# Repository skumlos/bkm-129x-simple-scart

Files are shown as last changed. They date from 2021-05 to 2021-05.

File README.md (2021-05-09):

The BKM-129X compatible with SCART instead of BNC.

Including a mono mixing circuit from SCART audio to RCA out, for monitors with internal audio in from option cards.

3D printable bracket here: https://www.thingiverse.com/thing:4460188

Requires Arduino Nano v3.0 loaded with the software from https://github.com/skumlos/bkm-129x-mcu

Revision history:

B: Fixed THS7374 filter bypass, change to Kicad 5

A: Initial revision

Copyright © 2020 Martin Hejnfelt <martin@hejnfelt.com>
This work is free. You can redistribute it and/or modify it under the
terms of the Do What The Fuck You Want To Public License, Version 2,
as published by Sam Hocevar. See the LICENSE file for more details.

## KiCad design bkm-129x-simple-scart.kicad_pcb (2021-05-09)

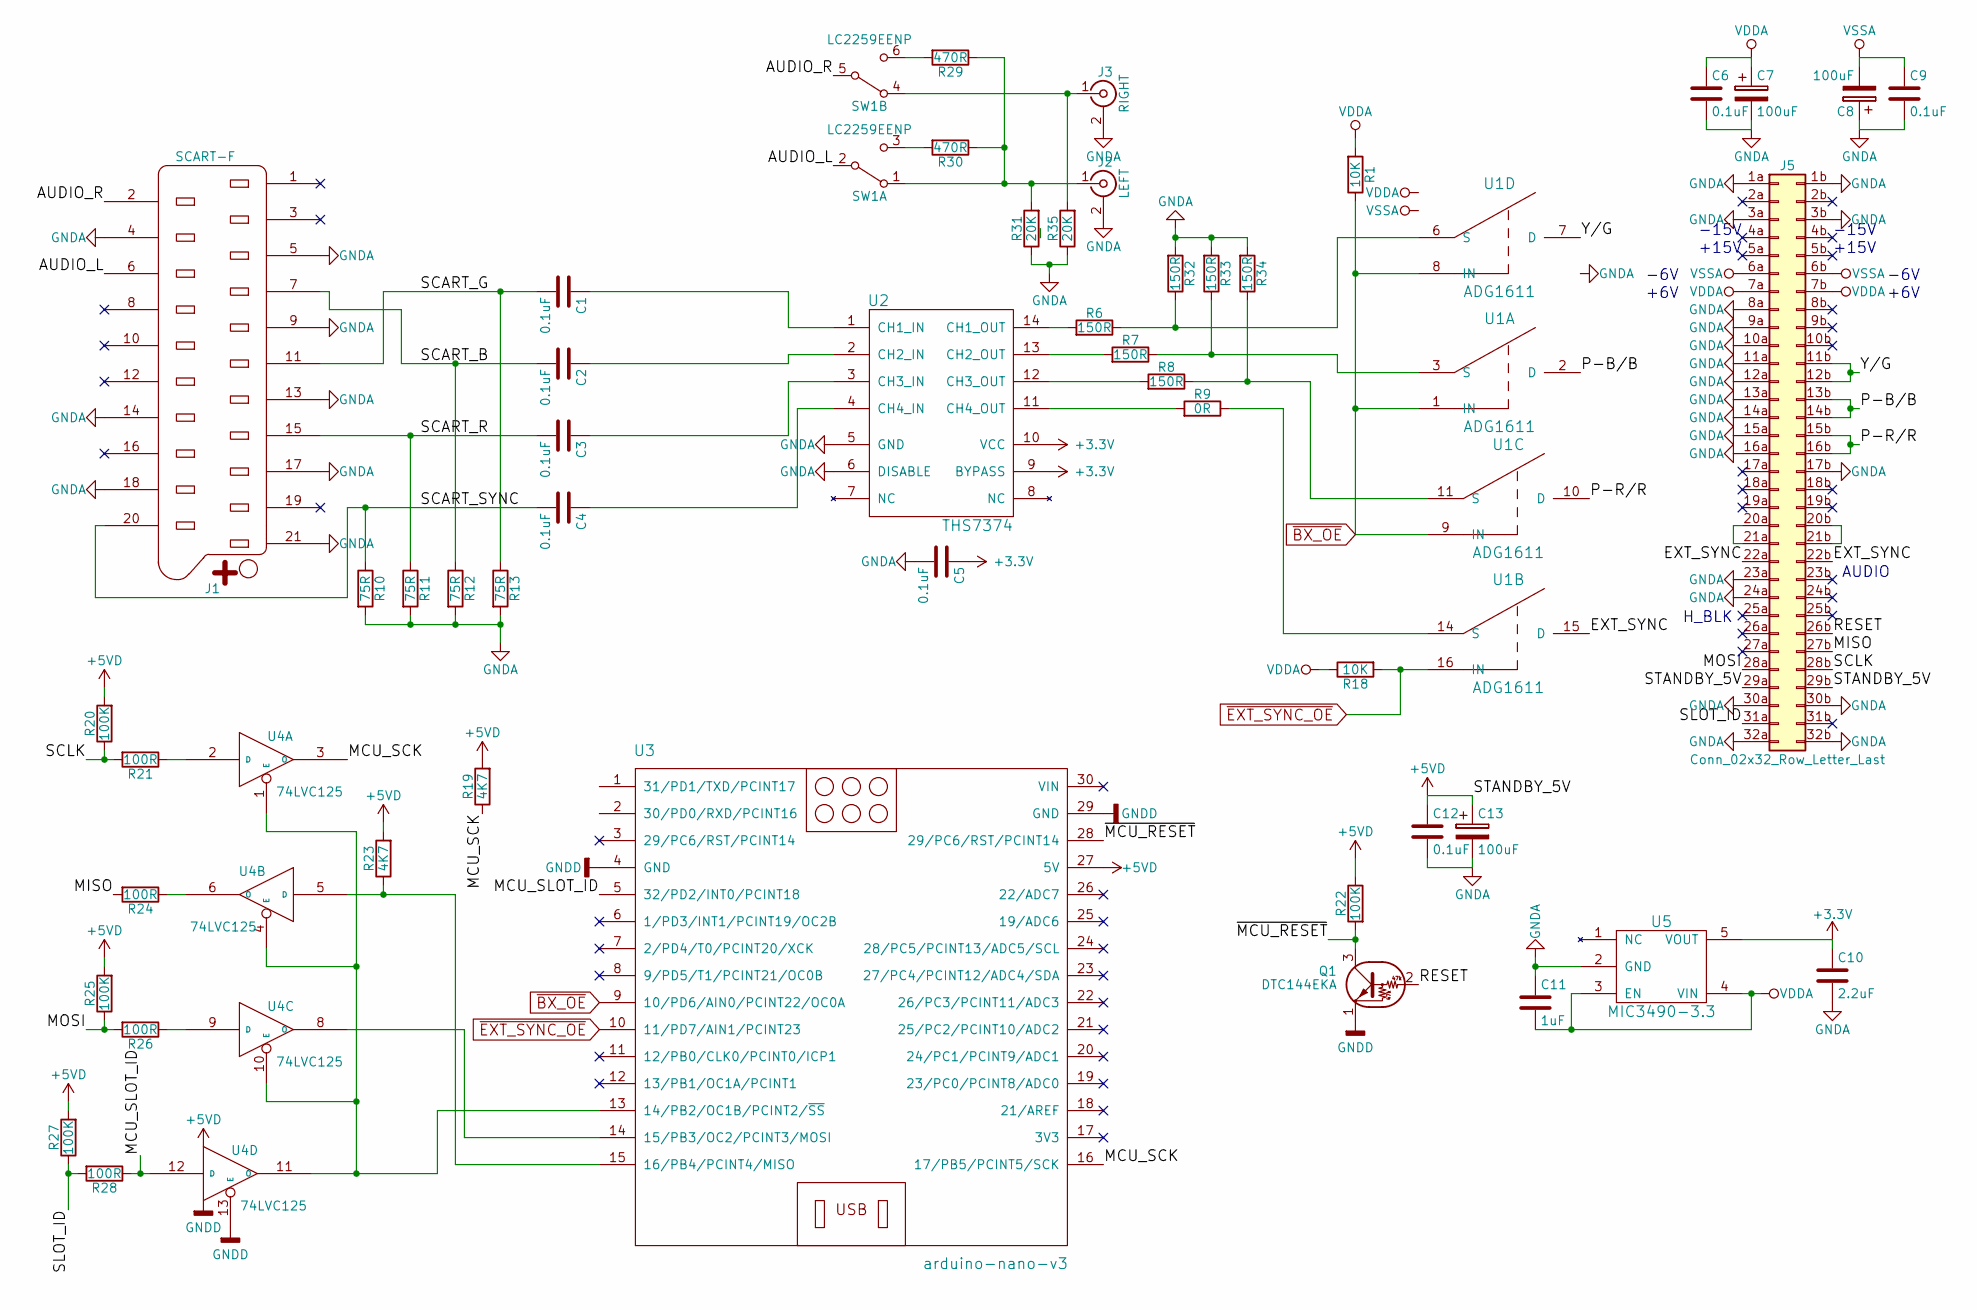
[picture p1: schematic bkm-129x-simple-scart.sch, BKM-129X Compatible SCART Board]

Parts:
C1, C2, C3, C4, C5, C6, C9, C12: 0.1uF; C_0805_HandSoldering
C7, C8, C13: 100uF; CP_Elec_6.3x5.3
C10: 2.2uF; C_0805_HandSoldering
C11: 1uF; C_0805_HandSoldering
J1: SCART-F; NINIGI-SCART-RA
J2: LEFT; RCJ-04X
J3: RIGHT; RCJ-04X
J5: Conn_02x32_Row_Letter_Last; DIN-41612-64P
Q1: DTC144EKA; SC-59_Handsoldering
R1, R18: 10K; R_0805_HandSoldering
R6, R7, R8, R32, R33, R34: 150R; R_0805_HandSoldering
R9: 0R; R_0805_HandSoldering
R10, R11, R12, R13: 75R; R_0805_HandSoldering
R19, R23: 4K7; R_0805_HandSoldering
R20, R22, R25, R27: 100K; R_0805_HandSoldering
R21, R24, R26, R28: 100R; R_0805_HandSoldering
R29, R30: 470R; R_0805_HandSoldering
R31, R35: 20K; R_0805_HandSoldering
SW1: LC2259EENP; LC2259
U1: ADG1611; TSSOP-16_4.4x5mm_Pitch0.65mm
U2: THS7374; TSSOP-14_4.4x5mm_Pitch0.65mm
U3: arduino-nano-v3
U4: 74LVC125; TSSOP-14_4.4x5mm_Pitch0.65mm
U5: MIC3490-3.3; SOT-23-5_HandSoldering

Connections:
+3V3: C5.1, C10.1, U2.9 (BYPASS), U2.10 (VCC), U5.5 (VOUT)
+5VD: C12.1, C13.1, J5.29a, J5.29b, R19.2, R20.2, R22.1, R23.2, R25.2, R27.2, U3.27 (5V), U4.14 (VCC)
/AUDIO_L: J1.6, SW1.2 (B)
/AUDIO_R: J1.2, SW1.5 (B)
/EXT_SYNC: J5.22a, J5.22b, U1.15 (D)
/MCU_SCK: R19.1, U3.16 (17/PB5/PCINT5/SCK), U4.3 (O)
/MCU_SLOT_ID: R28.1, U3.5 (32/PD2/INT0/PCINT18), U4.12 (D)
/MISO: J5.27b, R24.2
/MOSI: J5.28a, R25.1, R26.2
/P-B/B: J5.13b, J5.14b, U1.2 (D)
/P-R/R: J5.15b, J5.16b, U1.10 (D)
/RESET: J5.26b, Q1.2 (B)
/SCART_B: C2.2, J1.7, R12.1
/SCART_G: C1.2, J1.11, R13.1
/SCART_R: C3.2, J1.15, R11.1
/SCART_SYNC: C4.2, J1.20, R10.1
/SCLK: J5.28b, R20.1, R21.2
/SLOT_ID: J5.31a, R27.1, R28.2
/Y/G: J5.11b, J5.12b, U1.7 (D)
/~MCU_RESET: Q1.3 (C), R22.2, U3.28 (29/PC6/RST/PCINT14)
unnamed: C1.1, U2.1 (CH1_IN)
unnamed: C2.1, U2.2 (CH2_IN)
unnamed: C3.1, U2.3 (CH3_IN)
unnamed: C4.1, U2.4 (CH4_IN)
unnamed: J2.1 (In), R29.1, R30.1, R31.2, SW1.1 (A)
unnamed: J3.1 (In), R35.2, SW1.4 (A)
unnamed: J5.20a, J5.21a
unnamed: J5.20b, J5.21b
unnamed: R6.2, U2.14 (CH1_OUT)
unnamed: R7.2, U2.13 (CH2_OUT)
unnamed: R8.2, U2.12 (CH3_OUT)
unnamed: R9.1, U1.14 (S)
unnamed: R9.2, U2.11 (CH4_OUT)
unnamed: R21.1, U4.2 (D)
unnamed: R23.1, U3.15 (16/PB4/PCINT4/MISO), U4.5 (D)
unnamed: R24.1, U4.6 (O)
unnamed: R26.1, U4.9 (D)
unnamed: R29.2, SW1.6 (C)
unnamed: R30.2, SW1.3 (C)
unnamed: R6.1, R32.1, U1.6 (S)
unnamed: R7.1, R33.1, U1.3 (S)
unnamed: R8.1, R34.1, U1.11 (S)
unnamed: U3.13 (14/PB2/OC1B/PCINT2/~SS), U4.1 (E), U4.4 (E), U4.10 (E), U4.11 (O)
unnamed: U3.14 (15/PB3/OC2/PCINT3/MOSI), U4.8 (O)
VDD: C6.1, C7.1, C11.2, J5.7a, J5.7b, R1.2, R18.1, U1.13 (VDD), U5.3 (EN), U5.4 (VIN)
VSS: C8.2, C9.1, J5.6a, J5.6b, U1.4 (VSS)
~BX_OE: R1.1, U1.1 (IN), U1.8 (IN), U1.9 (IN), U3.9 (10/PD6/AIN0/PCINT22/OC0A)
~EXT_SYNC_OE: R18.2, U1.16 (IN), U3.10 (11/PD7/AIN1/PCINT23)

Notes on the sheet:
-15V
+15V
-6V
+6V
AUDIO
H_BLK

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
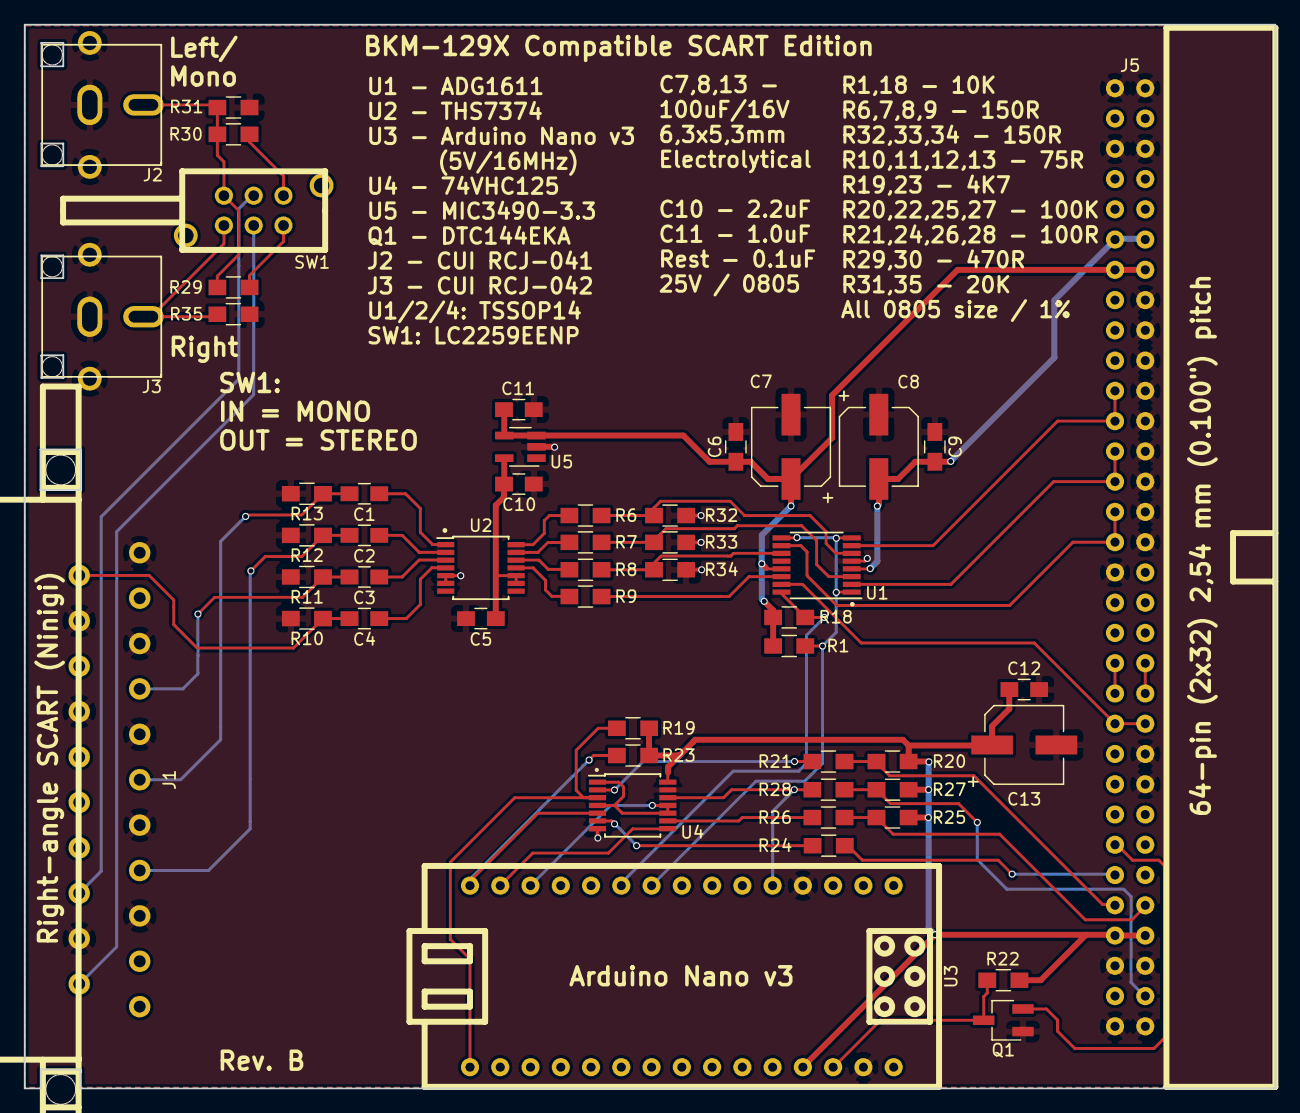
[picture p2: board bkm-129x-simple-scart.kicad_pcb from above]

Board: 2 copper layers, 105.0 x 89.3 mm, 51 parts (0 on the bottom side), 49 nets.

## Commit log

2020-03-01 Fixed some footprints
    [bkm-129x-simple-scart.kicad_pcb, bkm-129x-simple-scart.sch]
2020-03-01 Fixed SCART pad size and added signal names
    [bkm-129x-simple-scart.kicad_pcb, bkm-129x-simple-scart.sch]
2020-06-13 Added audio switch, enlarge holes for SCART fasteners
    [bkm-129x-simple-scart.kicad_pcb, bkm-129x-simple-scart.sch]
2020-06-14 Fixed erroneous RCA plug part number
    [bkm-129x-simple-scart.kicad_pcb]
2020-06-19 Aligned partslist text
    [bkm-129x-simple-scart.kicad_pcb]
2021-05-09 Revision B
    [bkm-129x-simple-scart.kicad_pcb, bkm-129x-simple-scart.sch]
